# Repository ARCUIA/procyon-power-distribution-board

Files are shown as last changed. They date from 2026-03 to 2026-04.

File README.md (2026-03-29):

# procyon-power-distribution-board
Power distribution board responsible for managing power for the Atlas flight controller, up to 3 FPV camera + VTX systems, a radio module, and a DC motor. Toggle-able camera power to save battery. Support for High-side switching, allowing for chassis grounding on VTX modules.

### V1 Typical Application
- Battery: 2S LiPo 5000 mAh
- Flight Controller: Atlas V3
     - Input Voltage: 5V
     - Inpue Current (max): 250 mAh
- Motor: BLDC RS-380SH-4535
     - Input Voltage: 5V
     - Input Current: <1 amp
- Radio: RFD900X
     - Input Voltage: 5V
     - Input Current: 1 amp
- FPV Systems: CADDX Walksnail Avatar HD Pro
     - Input Voltage: Battery (Minimum 6V)
     - Input Current: 0.5-1 amp

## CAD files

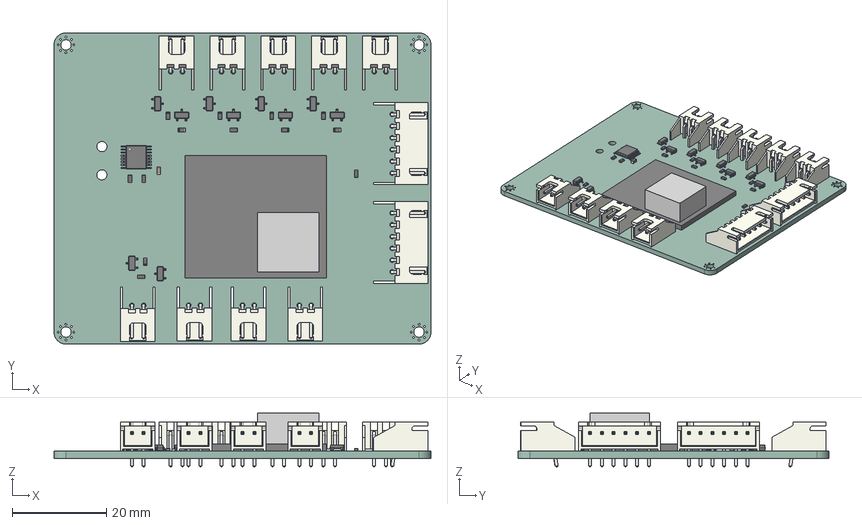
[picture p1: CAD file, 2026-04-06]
procyon-power-distribution-board/procyon-power-distribution-board.step
80.0 x 66.0 x 11.4 mm
TSSOP-16_4.4x5mm_P0.65mm
R_0603_1608Metric x 13
C_0603_1608Metric
JST_XH_S6B-XH-A-1_1x06_P2.50mm_Horizontal x 2
JST_XH_S2B-XH-A-1_1x02_P2.50mm_Horizontal x 9
SOT-23 x 10
procyon-power-distribution-board_PCB

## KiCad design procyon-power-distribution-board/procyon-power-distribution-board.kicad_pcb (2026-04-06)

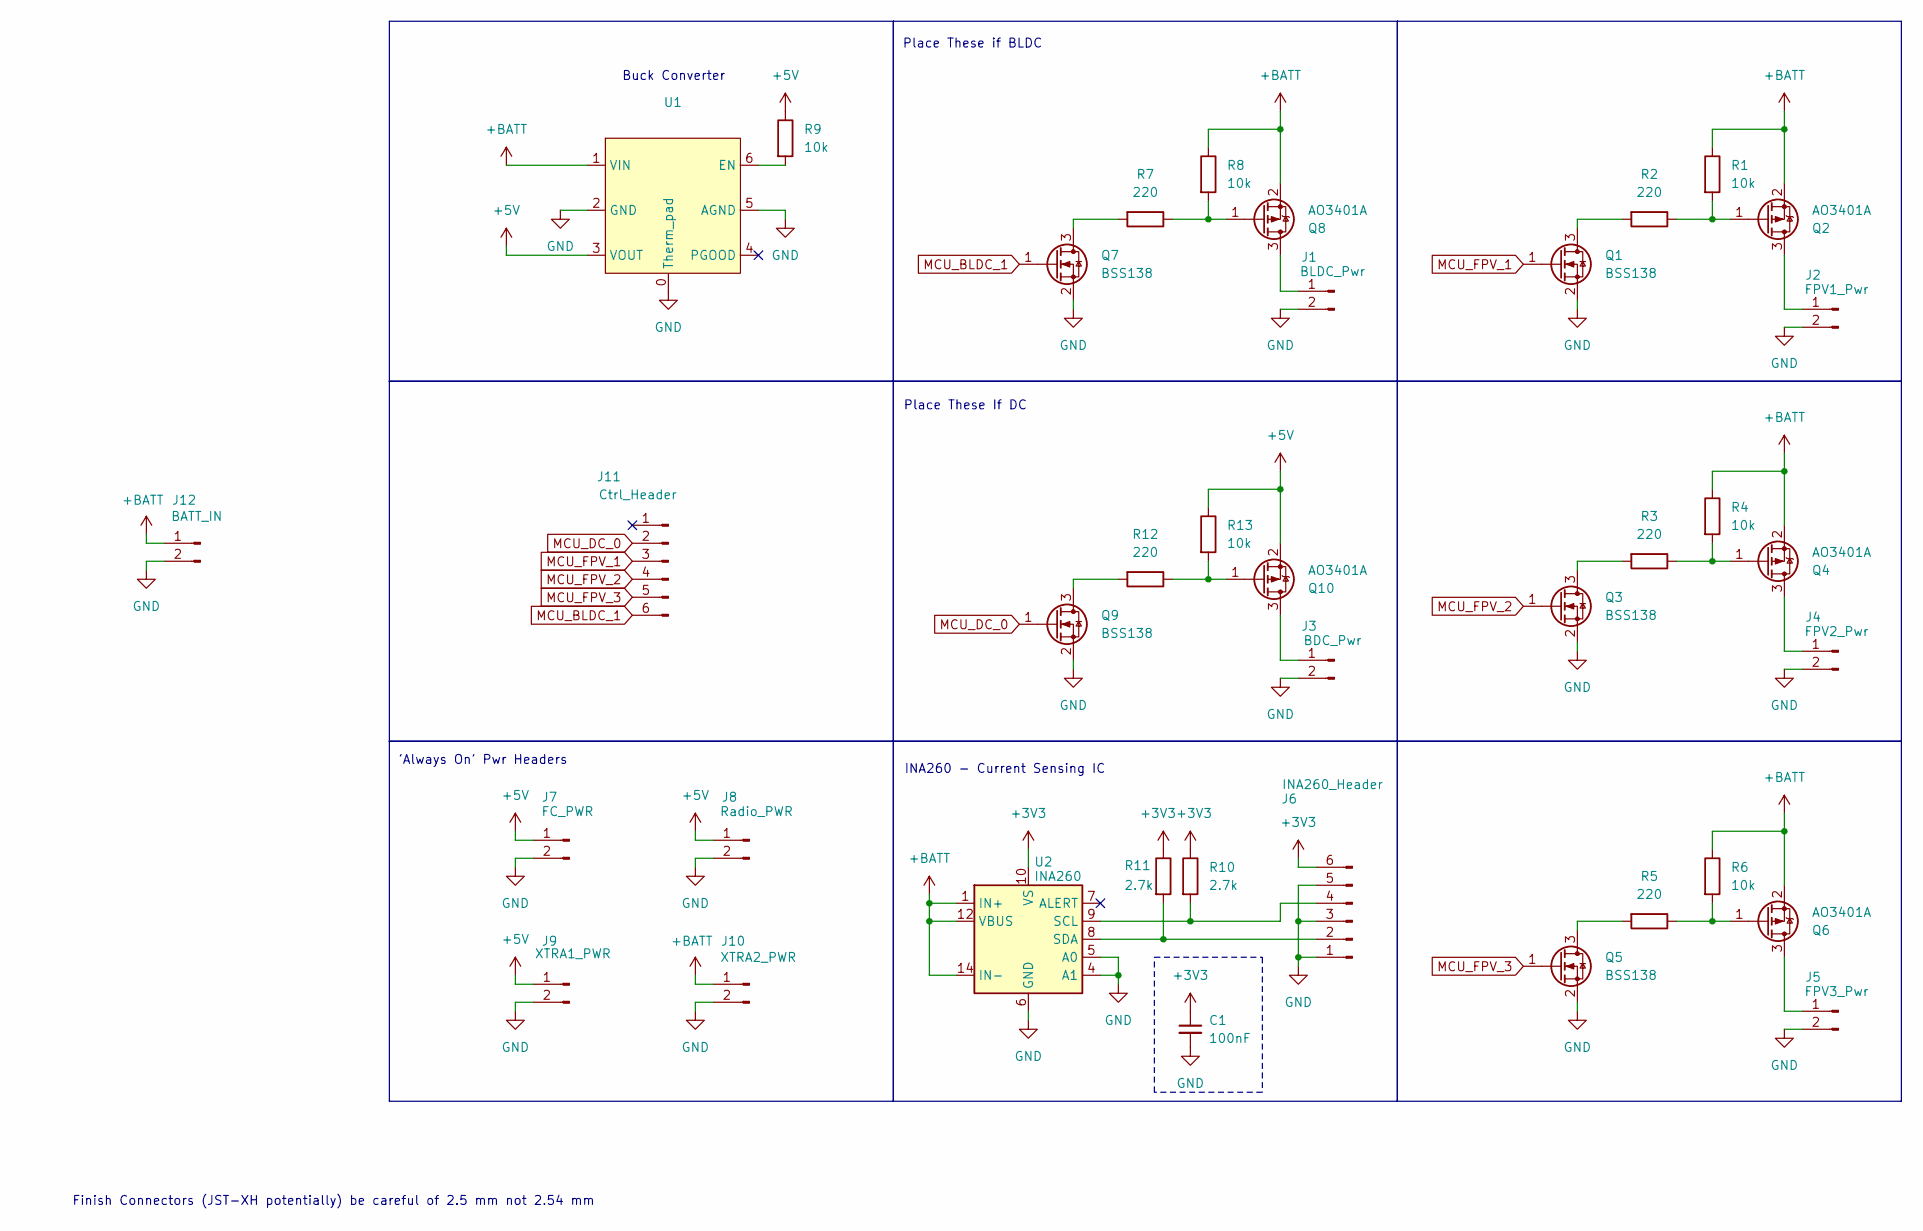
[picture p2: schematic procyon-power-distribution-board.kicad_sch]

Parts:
C1: 100nF; C_0603_1608Metric_Pad1.08x0.95mm_HandSolder
J1: BLDC_Pwr; JST_XH_S2B-XH-A-1_1x02_P2.50mm_Horizontal
J2: FPV1_Pwr; JST_XH_S2B-XH-A-1_1x02_P2.50mm_Horizontal
J3: BDC_Pwr; JST_XH_S2B-XH-A-1_1x02_P2.50mm_Horizontal
J4: FPV2_Pwr; JST_XH_S2B-XH-A-1_1x02_P2.50mm_Horizontal
J5: FPV3_Pwr; JST_XH_S2B-XH-A-1_1x02_P2.50mm_Horizontal
J6: INA260_Header; JST_XH_S6B-XH-A-1_1x06_P2.50mm_Horizontal
J7: FC_PWR; JST_XH_S2B-XH-A-1_1x02_P2.50mm_Horizontal
J8: Radio_PWR; JST_XH_S2B-XH-A-1_1x02_P2.50mm_Horizontal
J9: XTRA1_PWR; JST_XH_S2B-XH-A-1_1x02_P2.50mm_Horizontal
J10: XTRA2_PWR; JST_XH_S2B-XH-A-1_1x02_P2.50mm_Horizontal
J11: Ctrl_Header; JST_XH_S6B-XH-A-1_1x06_P2.50mm_Horizontal
J12: BATT_IN; SolderWire-1.5sqmm_1x02_P6mm_D1.7mm_OD3mm
Q1, Q3, Q5, Q7, Q9: BSS138; SOT-23
Q2, Q4, Q6, Q8, Q10: AO3401A; SOT-23
R1, R4, R6, R8, R9, R13: 10k; R_0603_1608Metric_Pad0.98x0.95mm_HandSolder
R2, R3, R5, R7, R12: 220; R_0603_1608Metric_Pad0.98x0.95mm_HandSolder
R10, R11: 2.7k; R_0603_1608Metric_Pad0.98x0.95mm_HandSolder
U1: CKCS_CK2416
U2: INA260; TSSOP-16_4.4x5mm_P0.65mm

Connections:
+3V3: C1.1, J6.6, R10.1, R11.1, U2.10 (VS)
+5V: J7.1, J8.1, J9.1, Q10.2 (S), R9.1, R13.1, U1.3 (VOUT)
+BATT: J10.1, J12.1, Q2.2 (S), Q4.2 (S), Q6.2 (S), Q8.2 (S), R1.1, R4.1, R6.1, R8.1, U1.1 (VIN), U2.1 (IN+), U2.2 (IN+), U2.3 (IN+), U2.12 (VBUS), U2.14 (IN-), U2.15 (IN-), U2.16 (IN-)
GND: C1.2, J1.2, J2.2, J3.2, J4.2, J5.2, J6.1, J6.3, J6.5, J7.2, J8.2, J9.2, J10.2, J12.2, Q1.2 (S), Q3.2 (S), Q5.2 (S), Q7.2 (S), Q9.2 (S), U1.0 (Therm_pad), U1.2 (GND), U1.5 (AGND), U2.4 (A1), U2.5 (A0), U2.6 (GND), U2.11 (GND)
MCU_BLDC_1: J11.6, Q7.1 (G)
MCU_DC_0: J11.2, Q9.1 (G)
MCU_FPV_1: J11.3, Q1.1 (G)
MCU_FPV_2: J11.4, Q3.1 (G)
MCU_FPV_3: J11.5, Q5.1 (G)
unnamed: J1.1, Q8.3 (D)
unnamed: J2.1, Q2.3 (D)
unnamed: J3.1, Q10.3 (D)
unnamed: J4.1, Q4.3 (D)
unnamed: J5.1, Q6.3 (D)
unnamed: J6.2, R11.2, U2.8 (SDA)
unnamed: J6.4, R10.2, U2.9 (SCL)
unnamed: Q1.3 (D), R2.2
unnamed: Q2.1 (G), R1.2, R2.1
unnamed: Q3.3 (D), R3.2
unnamed: Q4.1 (G), R3.1, R4.2
unnamed: Q5.3 (D), R5.2
unnamed: Q6.1 (G), R5.1, R6.2
unnamed: Q7.3 (D), R7.2
unnamed: Q8.1 (G), R7.1, R8.2
unnamed: Q9.3 (D), R12.2
unnamed: Q10.1 (G), R12.1, R13.2
unnamed: R9.2, U1.6 (EN)

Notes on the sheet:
Place These If DC
Finish Connectors (JST-XH potentially) be careful of 2.5 mm not 2.54 mm
Buck Converter
'Always On' Pwr Headers
INA260 - Current Sensing IC
Place These if BLDC

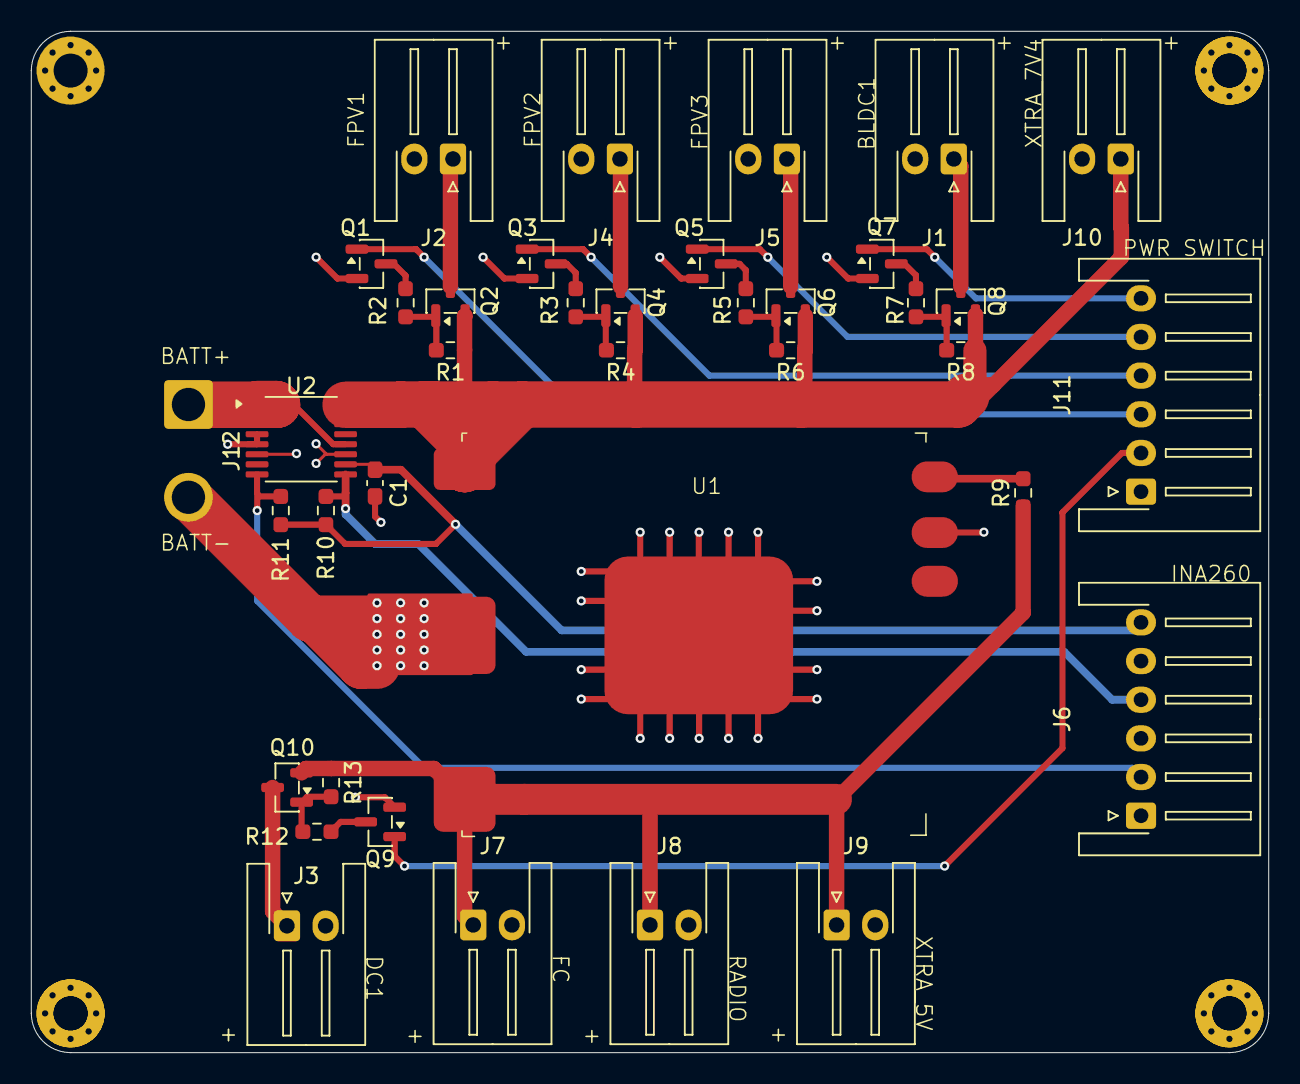
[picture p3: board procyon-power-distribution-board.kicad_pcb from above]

Board: 4 copper layers, 80.0 x 66.0 mm, 38 parts (0 on the bottom side), 27 nets.

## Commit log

2026-03-29 Enhance README with application details and features
    Expanded description of power distribution board features and added typical application details.
2026-04-02 init commit
    [procyon-power-distribution-board.kicad_pcb, procyon-power-distribution-board.kicad_sch]
2026-04-02 layout 1 for mosfets
    [procyon-power-distribution-board.kicad_pcb]
2026-04-02 added more structure. wip commit
    [procyon-power-distribution-board.kicad_pcb]
2026-04-03 Mostly Done with Schematic. Need to wire up connectors (JST-XH???) and add some more filtering caps to the INA260
    [procyon-power-distribution-board.kicad_pcb, procyon-power-distribution-board.kicad_sch]
2026-04-06 Major changes, mostly finished, needs mounting holes and drc then finished.
    [procyon-power-distribution-board.kicad_pcb, procyon-power-distribution-board.kicad_sch]
2026-04-06 V1 DONE!
    [procyon-power-distribution-board.kicad_pcb, procyon-power-distribution-board.kicad_sch]
2026-04-06 adding STEP file for the MechEs
    [procyon-power-distribution-board.step]
2026-04-06 adding production files
    [procyon-power-distribution-board.kicad_pcb]
2026-04-06 changed 3d model
    [procyon-power-distribution-board.kicad_pcb, procyon-power-distribution-board.step]
